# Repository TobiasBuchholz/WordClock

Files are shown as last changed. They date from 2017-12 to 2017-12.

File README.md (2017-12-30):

# Word Clock

Code for a simple DIY-version of the famous Word Clock based on a NodeMCU ESP8266 development board and Adafruit NeoPixels LED strip.
<br>
<br>
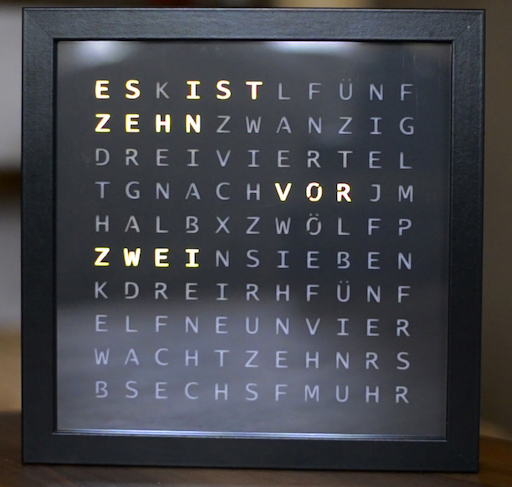
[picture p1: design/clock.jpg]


### Components
- [NodeMCU ESP8266](https://www.amazon.de/gp/product/B074Q2WM1Y/ref=oh_aui_detailpage_o04_s00?ie=UTF8&psc=1)
- [Adafruit NeoPixels LED strip](https://www.adafruit.com/product/1138)
- [300 Ohm resistor](https://www.amazon.de/gp/product/B009XOP5WM/ref=oh_aui_detailpage_o08_s00?ie=UTF8&psc=1)
- [1000uF 35V electrolytic capacitor](https://www.amazon.de/gp/product/B00ZBU6D5K/ref=oh_aui_detailpage_o07_s00?ie=UTF8&psc=1)
- [25 x 25 picture frame](https://www.amazon.de/IKEA-RIBBA-Rahmen-schwarz-23x23x4/dp/B00KGBMB6O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)
- [23 x 23 frosted acrylic glass](https://expresszuschnitt.de/PLEXIGLAS-weiss-milchglas)
- [23 x 23 adhesive film with plotted letters](https://github.com/TobiasBuchholz/WordClock/blob/master/design/letters_front.pdf)
- micro USB cable + power supply

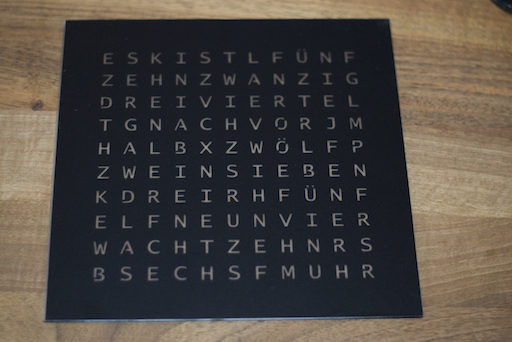
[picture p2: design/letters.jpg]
<br>
Be very carefull when putting the adhesive film on the frosted acrylic to prevent air bubbles.

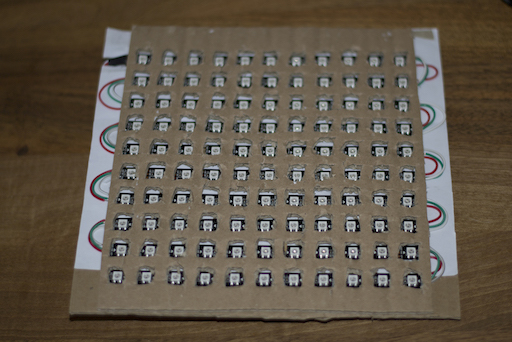
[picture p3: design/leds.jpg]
<br>
The LED strip needs to be cut and rearranged in a zig-zag pattern and reconnected with jumper cables.
I've also put a piece of cardboard with holes on top of the LEDs so the light from one LED will be directed towards a single letter, and not spread to adjacent ones.

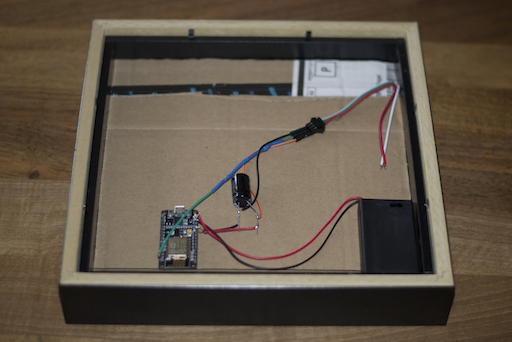
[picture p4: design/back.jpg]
<br>
I've also added a battery holder as power supply but it turns out on longer usage they are getting too weak too fast. So as far as you don't want to change the batteries every day the micro usb cable as power supply is the better way to go.

### Breadboard:

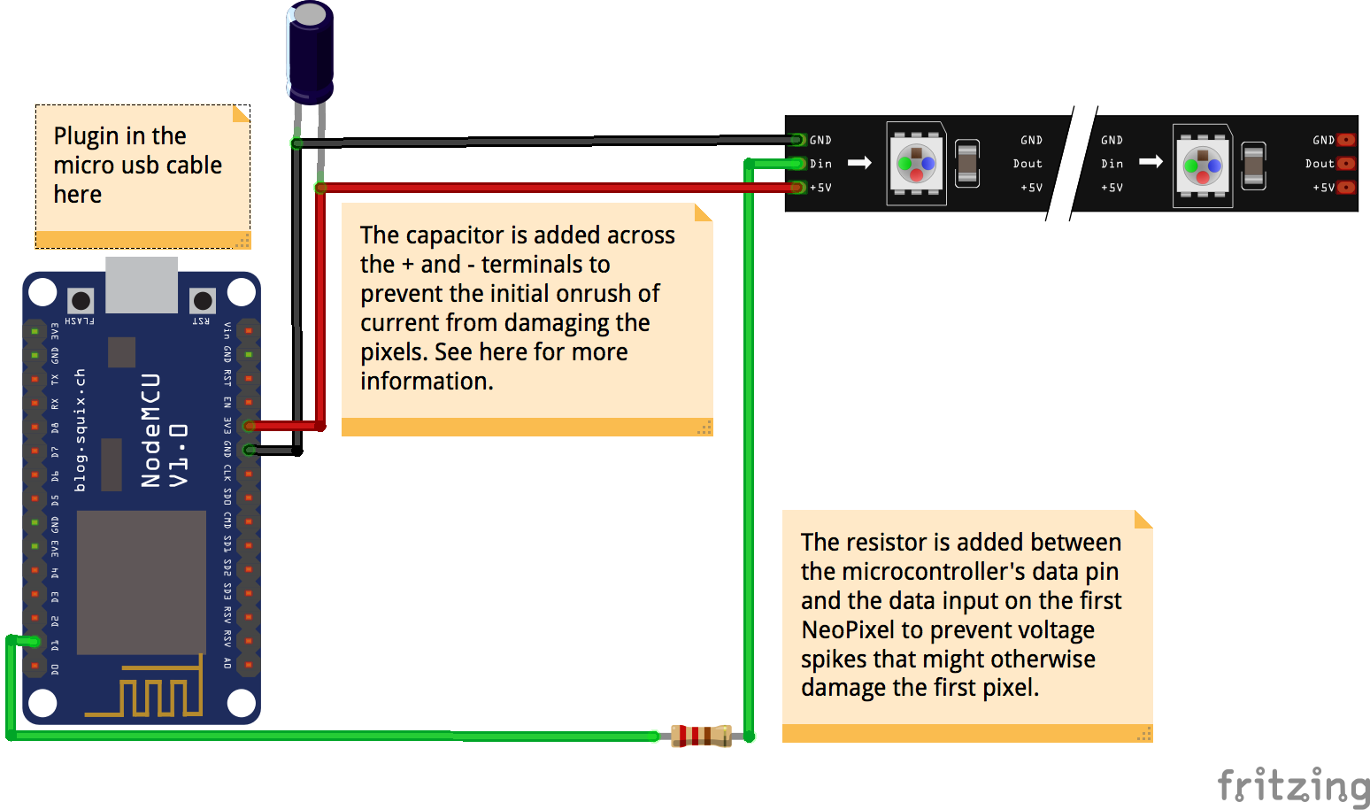
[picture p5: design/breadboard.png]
Breadboard

See [Adafruit guide](https://learn.adafruit.com/adafruit-neopixel-uberguide/powering-neopixels) for more information.

### NodeMCU code
The NodeMCU is the brain of the clock and is written in the Arduino environment.<br>
It connects to the local wifi via SSID and password and sets up a web sockets server to enable a real time connection between a client app and itself. After the connection is established it is possible to adjust the color and brightness of the LED strip. When the connection is closed the NodeMCU stores the adjusted values into its EPROM and retrieves them from now on after every boot.<br>
To display the time the NodeMCU queries the current time in an interval of 10 seconds from a NTP server, transforms it into a human readable sentence and enlightens the corresponding LEDs.

The following libraries are beeing used:
- ESP8266Wifi: https://github.com/esp8266/Arduino
- WebSocketsServer: https://github.com/Links2004/arduinoWebSockets
- Adafruit NeoPixels: https://github.com/adafruit/Adafruit_NeoPixel

### Android & iOS client
The clients provide the possibility to connect to the clock via the local wifi. After the connection is established it is possible to adjust the color and brightness of the LED strip in real time. There is also a Nightmode which decreases the brightness of the LEDs according to the configured value and time to save some energy. The clients are build with the crossplatform solution provided by [Xamarin](https://developer.xamarin.com/).

The following libraries are beeing used:
- ReactiveUI: https://github.com/reactiveui/ReactiveUI
- ReactiveUI.Fody: https://github.com/kswoll/ReactiveUI.Fody
- WebSockets.PCL: https://github.com/NVentimiglia/Websockets.PCL
- Akavache: https://github.com/akavache/Akavache

### Demo
Demo (https://www.youtube.com/watch?v=xTer7YWEIt0)

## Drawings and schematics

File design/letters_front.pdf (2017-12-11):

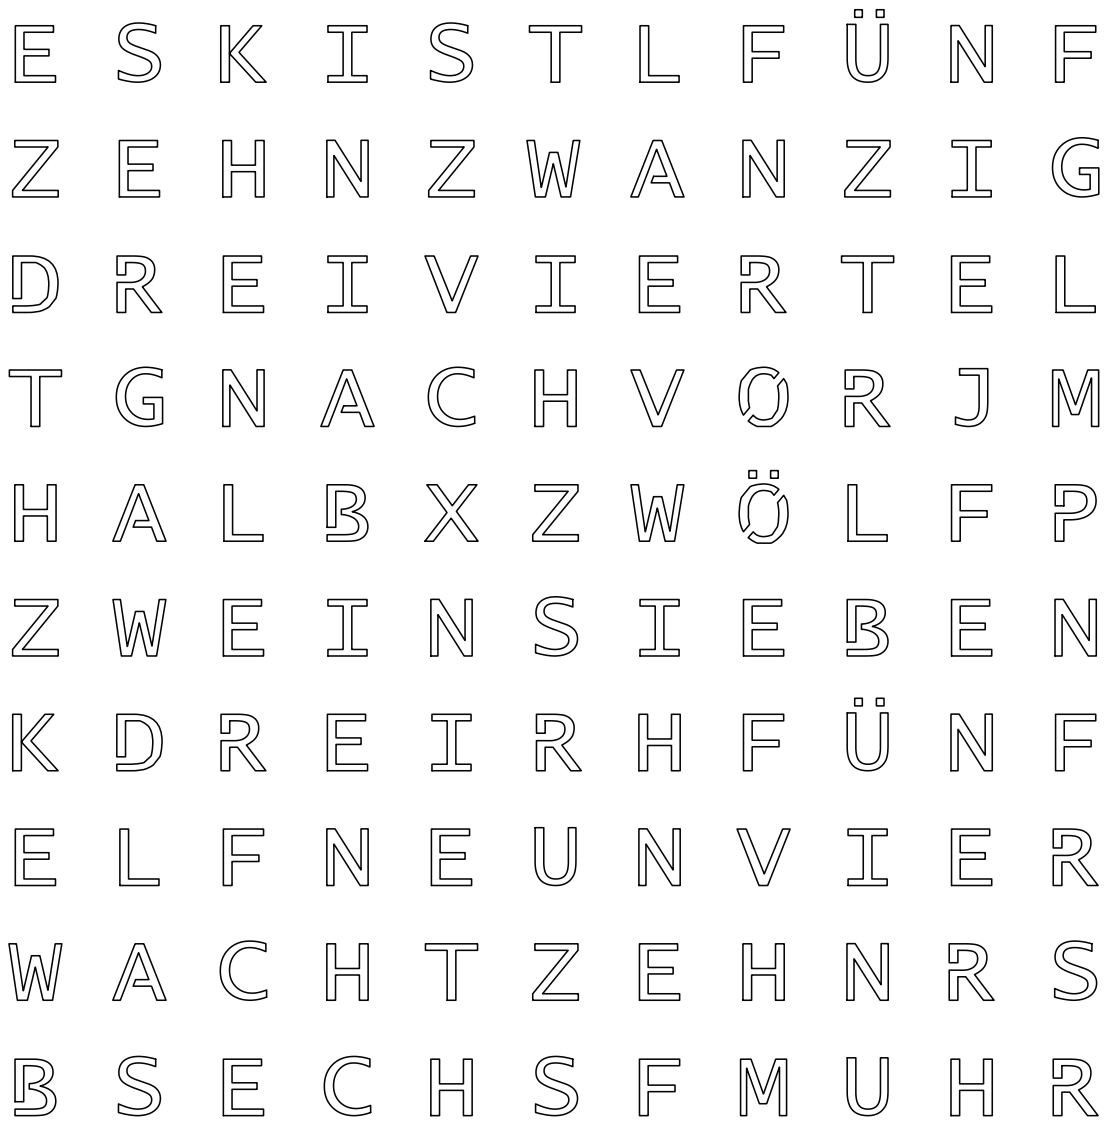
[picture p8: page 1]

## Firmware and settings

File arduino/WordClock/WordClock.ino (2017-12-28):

#include <Arduino.h>
#include <ESP8266WiFi.h>
#include <WebSocketsServer.h>
#include <WiFiUdp.h>
#include <RTClib.h>
#include <Adafruit_NeoPixel.h>
#include <EEPROM.h>

#define PIN 5
#define NUMPIXELS 110

int colorAlpha = 32;
int colorRed = 255;
int colorGreen = 255;
int colorBlue = 255;
bool isNightModeEnabled = false;
int nightModeBrightness = 1;
int nightModeFromTimeMillis = 3600000;
int nightModeToTimeMillis = 28800000;

unsigned long previousMillis = 0;
unsigned long previousMillisPixels = 0;
bool isConnectedToSocket = false;

void setup() {
  Serial.begin(115200);
  loadUserPrefs();
  connectToWifi();
  setupTimeDisplay();
  setupNTP();
  setupSocket();
}

void loop() {
  unsigned long currentMillis = millis();
  if (currentMillis - previousMillis >= 10000) {
    previousMillis = currentMillis;
    fetchTimeFromNTP();
    displayTimeSentence();
  }

  if (isConnectedToSocket && currentMillis - previousMillisPixels >= 50) {
    previousMillisPixels = currentMillis;
    displayTimeSentence();
  }

  loopSocket();
}

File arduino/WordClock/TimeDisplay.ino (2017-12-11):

char board[] = "ESKISTLFUNFGIZNAWZNHEZDREIVIERTELMJROVHCANGTHALBQZWOLFPNEBEISNIEWZKDREIRHFUNFREIVNUENFLEWACHTZEHNRSRHUMFSHCESB";

int es[] = { 0, 1, -1, -1, -1, -1, -1, -1, -1, -1, -1, -1 };
int ist[] = { 3, 4, 5, -1, -1, -1, -1, -1, -1, -1, -1, -1 };
int fuenf_minutes[] = { 7, 8, 9, 10, -1, -1, -1, -1, -1, -1, -1, -1 };
int zehn_minutes[] = { 21, 20, 19, 18, -1, -1, -1, -1, -1, -1, -1, -1 };
int zwanzig_minutes[] = { 17, 16, 15, 14, 13, 12, 11, -1, -1, -1, -1, -1 };
int dreiviertel[] = { 22, 23, 24, 25, 26, 27, 28, 29, 30, 31, 32, -1 };
int viertel[] = { 26, 27, 28, 29, 30, 31, 32, -1, -1, -1, -1, -1 };
int nach[] = { 41, 40, 39, 38, -1, -1, -1, -1, -1, -1, -1, -1 };
int vor[] = { 37, 36, 35, -1, -1, -1, -1, -1, -1, -1, -1, -1};
int halb[] = { 44, 45, 46, 47, -1, -1, -1, -1, -1, -1, -1, -1 };
int uhr[] = { 101, 100, 99, -1, -1, -1, -1, -1, -1, -1, -1, -1 };
int ein[] = { 63, 62, 61, -1, -1, -1, -1, -1, -1, -1, -1, -1 };

int hourMap[][12] = { { 63, 62, 61, 60, -1, -1, -1, -1, -1, -1, -1, -1 }, // eins
                      { 65, 64, 63, 62, -1, -1, -1, -1, -1, -1, -1, -1 }, // zwei
                      { 67, 68, 69, 70, -1, -1, -1, -1, -1, -1, -1, -1 }, // drei
                      { 80, 79, 78, 77, -1, -1, -1, -1, -1, -1, -1, -1 }, // vier
                      { 73, 74, 75, 76, -1, -1, -1, -1, -1, -1, -1, -1 }, // fuenf
                      { 104, 105, 106, 107, 108, -1, -1, -1, -1, -1, -1, -1 }, // sechs
                      { 60, 59, 58, 57, 56, 55, -1, -1, -1, -1, -1, -1 }, // sieben
                      { 89, 90, 91, 92, -1, -1, -1, -1, -1, -1, -1, -1 }, // acht
                      { 84, 83, 82, 81, -1, -1, -1, -1, -1, -1, -1, -1 }, // neun
                      { 93, 94, 95, 96, -1, -1, -1, -1, -1, -1, -1, -1 }, // zehn
                      { 87, 86, 85, -1, -1, -1, -1, -1, -1, -1, -1, -1 }, // elf
                      { 49, 50, 51, 52, 53, -1, -1, -1, -1, -1, -1, -1 } // zwoelf
                    };

Adafruit_NeoPixel pixels = Adafruit_NeoPixel(NUMPIXELS, PIN, NEO_GRB + NEO_KHZ800); 
bool pixelValues[NUMPIXELS];

void setupTimeDisplay() {
  pixels.begin();
}

void displayTimeSentence() {
  reset();
  setWord(es);
  setWord(ist);
  setMinute();
  setHour();
  setUhr();
  setPixelBrightness();
  showPixels();
  Serial.println();
}

void reset() {
  for(int i=0; i<NUMPIXELS; i++) {
    pixelValues[i] = false;
  }
}

void setWord(int wrd[]) {
  for (int i=0; i< 12; i++) {
    int pixel = wrd[i];
    if(pixel >= 0 && pixel < 111) {
      pixelValues[pixel] = true;
      Serial.print(board[pixel]);
    }
  }
  Serial.print(" ");
}

void setMinute() {
  if (ntpMinute > 2 && ntpMinute < 8) {
    setWord(fuenf_minutes);
    setWord(nach);
  } else if (ntpMinute > 7 && ntpMinute < 13) {
    setWord(zehn_minutes);
    setWord(nach);
  } else if (ntpMinute > 12 && ntpMinute < 18) {
    setWord(viertel);
  } else if (ntpMinute > 17 && ntpMinute < 23) {
    setWord(zehn_minutes);
    setWord(vor);
    setWord(halb);
  } else if (ntpMinute > 22 && ntpMinute < 28) {
    setWord(fuenf_minutes);
    setWord(vor);
    setWord(halb);
  } else if (ntpMinute > 27 && ntpMinute < 33) {
    setWord(halb);
  } else if (ntpMinute > 32 && ntpMinute < 38) {
    setWord(fuenf_minutes);
    setWord(nach);
    setWord(halb);
  } else if (ntpMinute > 37 && ntpMinute < 43) {
    setWord(zehn_minutes);
    setWord(nach);
    setWord(halb);
  } else if (ntpMinute > 42 && ntpMinute < 48) {
    setWord(dreiviertel);
  } else if (ntpMinute > 47 && ntpMinute < 53) {
    setWord(zehn_minutes);
    setWord(vor);
  } else if (ntpMinute > 52 && ntpMinute < 58) {
    setWord(fuenf_minutes);
    setWord(vor);
  }
}

void setHour() {
  int h = ntpHour;
  if(h>12) h=h-12;
  if(h==0) h=12;
  
  if(h == 1 && ntpMinute < 3 || (h == 0 || h == 12) && ntpMinute > 57) {
    setWord(ein);
  } else if (ntpMinute >= 0 && ntpMinute < 13) {
    setWord(hourMap[h - 1]);
  } else {    
    setWord(hourMap[h == 12 ? 0 : h]);
  }
}

void setUhr() {
  if (ntpMinute > 57 || ntpMinute < 3) {
    setWord(uhr);
  }
}

void setPixelBrightness() {
  int currentTimeMillis = ntpHour*3600000 + ntpMinute*60000;
  
  if(isNightModeEnabled && 
    ((nightModeFromTimeMillis < nightModeToTimeMillis && currentTimeMillis > nightModeFromTimeMillis && currentTimeMillis < nightModeToTimeMillis) ||
     (nightModeFromTimeMillis > nightModeToTimeMillis && (currentTimeMillis > nightModeFromTimeMillis || currentTimeMillis < nightModeToTimeMillis)))) {
     pixels.setBrightness(nightModeBrightness);     
  } else {
    pixels.setBrightness(colorAlpha);      
  } 
}

void showPixels() {
  for(int i=0; i<NUMPIXELS; i++) {  
    pixels.setPixelColor(i, pixelValues[i] ? pixels.Color(colorRed, colorGreen, colorBlue) : pixels.Color(0, 0, 0)); 
  }
  pixels.show();
  Serial.println();
}

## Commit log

2017-12-28 fix initial night mode picker height
    -> on android the picker was visible although it shouldn’t because the height wasn’t set before the IsNightModeEnabled change event was fired
2017-12-30 remove unnecessary bracket from readme
2017-12-30 add bracket again..
2025-04-13 fix date time saving mode + fix app build
    [NTP.ino]
